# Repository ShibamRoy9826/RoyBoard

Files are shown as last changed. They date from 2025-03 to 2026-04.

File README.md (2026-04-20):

# RoyBoard 





## Description

Its a mechanical keyboard that I made from scratch! Its basically a 75% tenkeyless keyboard with 81 keys in total, with 3 additional rotary encoders for different tasks such as volume control, brightness control and scrolling, of course these functionalities are subject to change. It has a few neopixels too! not per key RGB though, because i rarely use backlight and it was pretty daunting to route them up, considering the fact that i just started hardware back then, the ones which I have are meant for aesthetics. Currently, I have dropped the plan to solder them because I mirrored the pinouts and it will be a terrible mess to solder them, I guess I am still satisfied with how it turned out though. 

## Features 

- ~Includes RGB lights (not per key RGB)~ (Not soldered)
- Has 3 rotary encoders for different functions
    - Media playback
    - Brightness
    - Volume
    - Scrolling
    - DWM tag switching(Any other wm works)
- 2 Layer keyboard (as of now, may add more in future if needed)
- Consists of 81 keys in total + 3 clickable rotary encoders, a 75%-ish Tenkeyless keyboard
- 5 degree tilt stand for a comfortable typing experience

## Real Life Pics

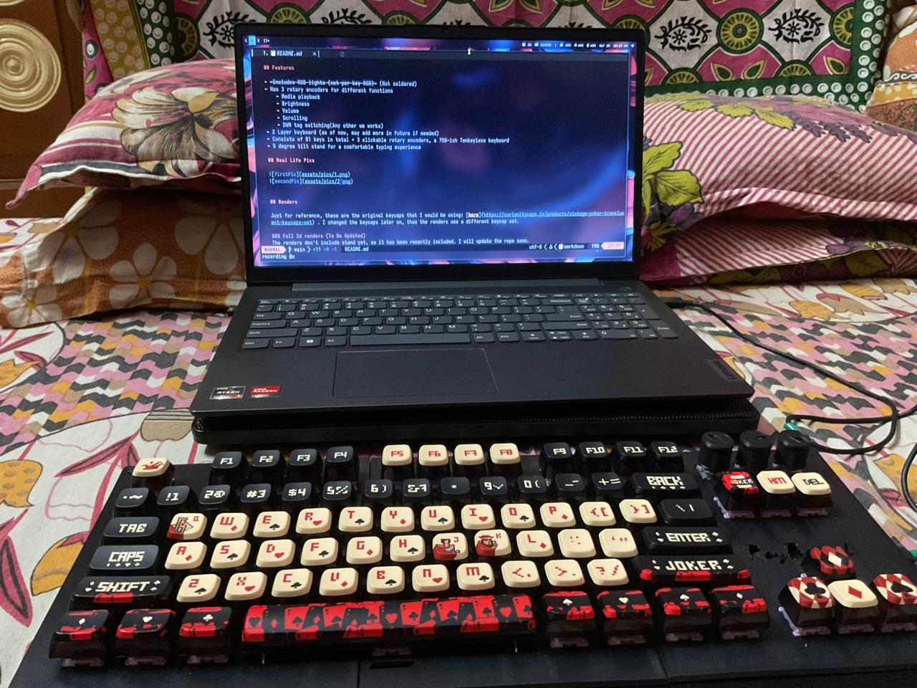
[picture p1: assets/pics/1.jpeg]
firstPic


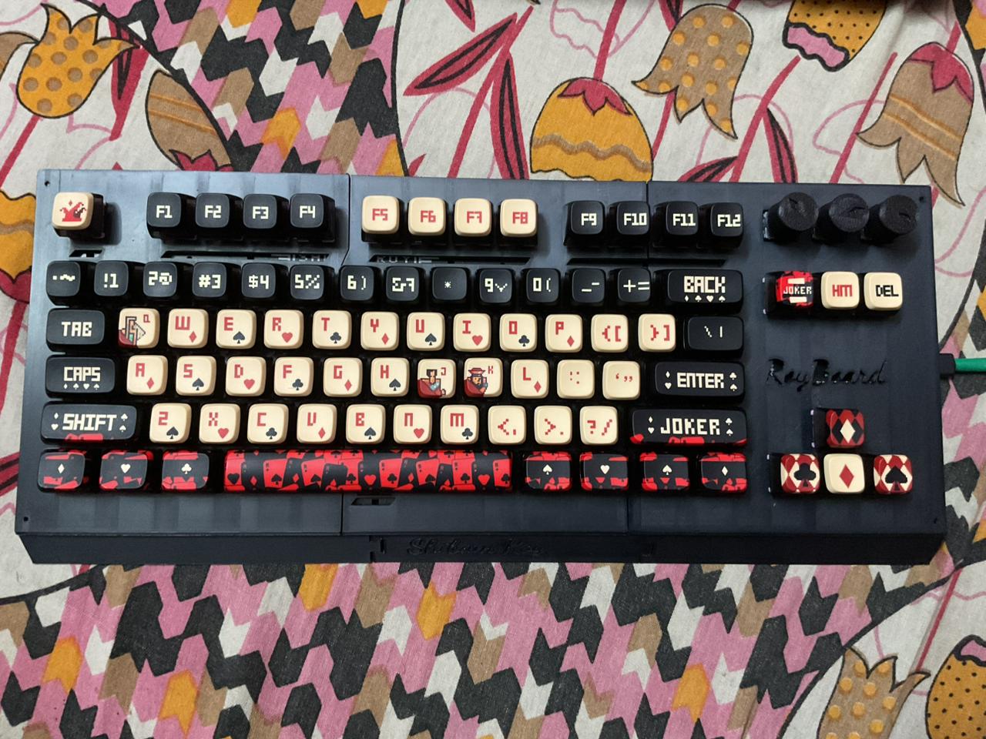
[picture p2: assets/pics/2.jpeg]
secondPic


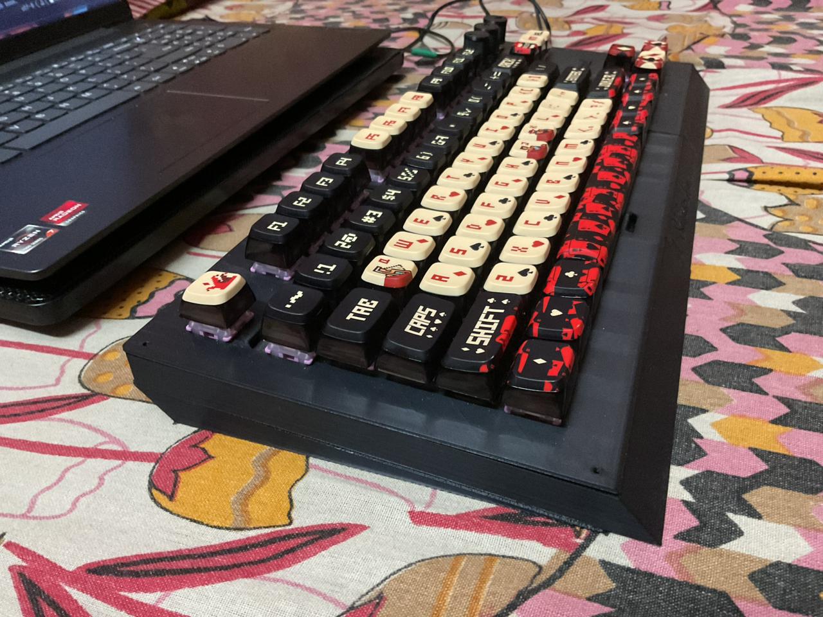
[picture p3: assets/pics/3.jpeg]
thirdPic


## Renders

Just for reference, these are the original keycaps that I would be using: [here](https://curiositycaps.in/products/vintage-poker-translucent-keycaps-set) . I changed the keycaps later on, thus the renders use a different keycap set.

### Full 3d renders (To Be Updated)
The renders don't include stand yet, as it has been recently included. I will update the repo soon.

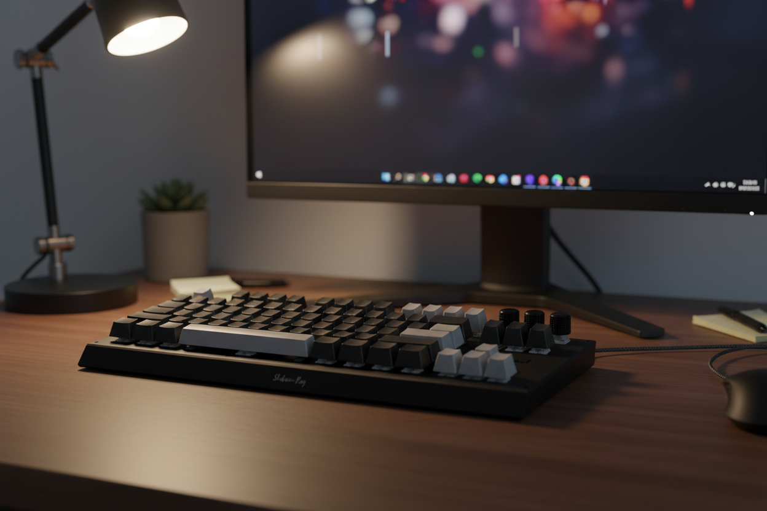
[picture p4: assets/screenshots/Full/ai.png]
ai


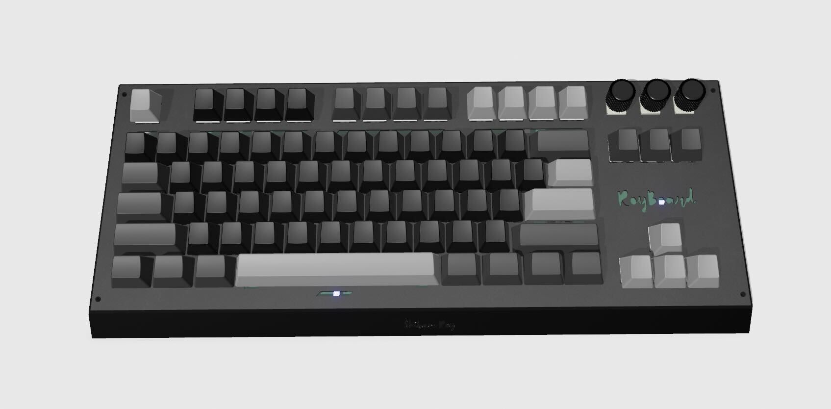
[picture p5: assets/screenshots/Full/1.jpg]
first


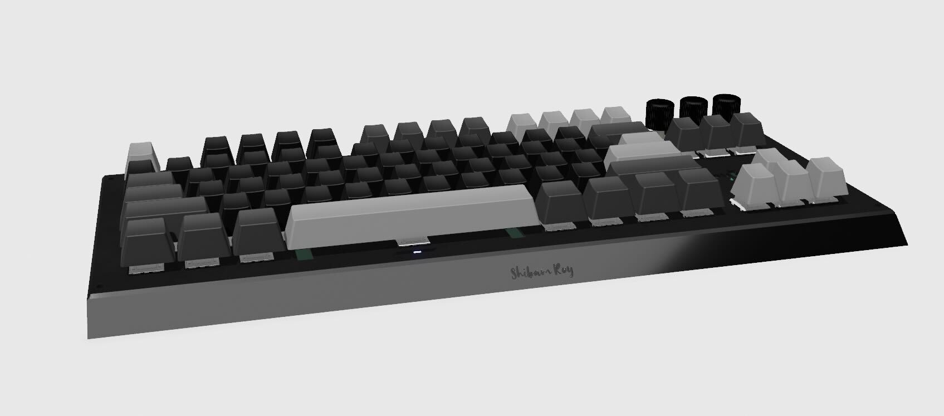
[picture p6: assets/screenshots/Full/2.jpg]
second


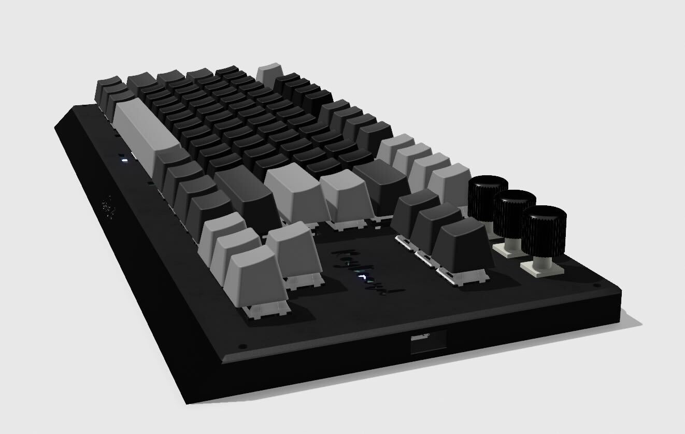
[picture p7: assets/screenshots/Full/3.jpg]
third


### Bottom case

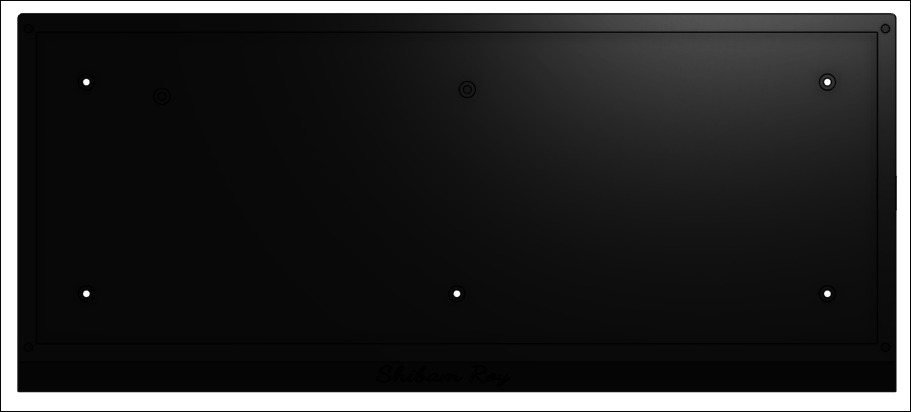
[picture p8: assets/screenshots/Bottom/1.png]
bottom

bottom1
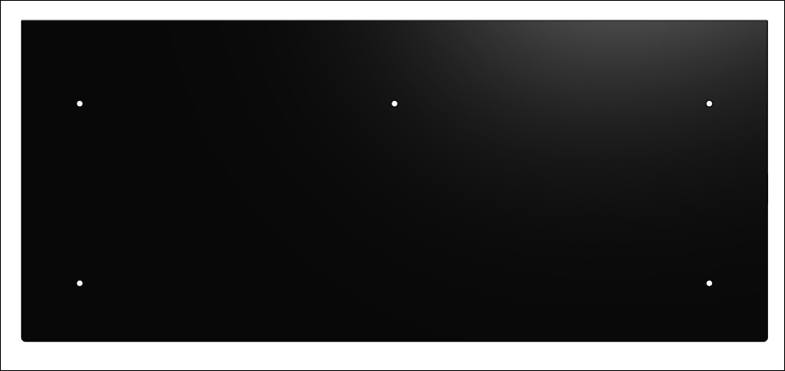
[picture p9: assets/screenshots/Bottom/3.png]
bottom2


### Top plate

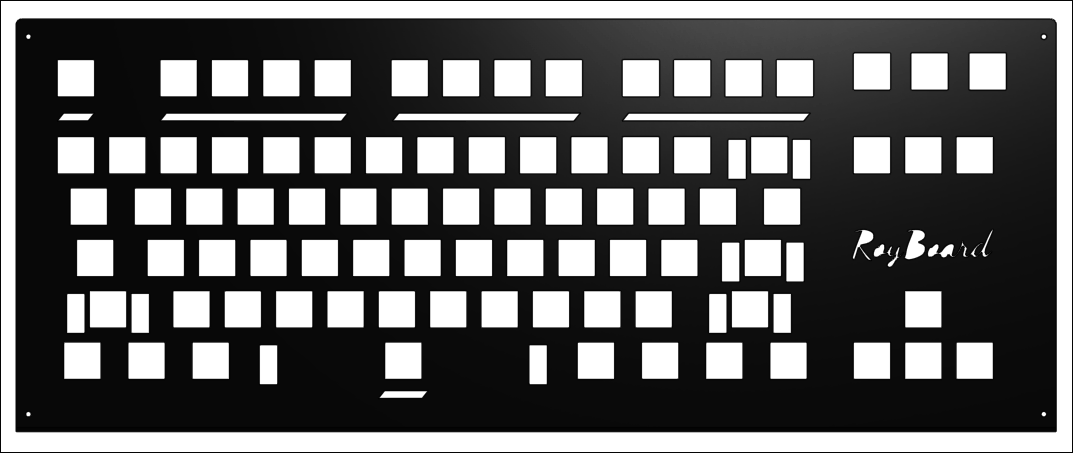
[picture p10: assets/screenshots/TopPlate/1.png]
top


### Stand

stand1
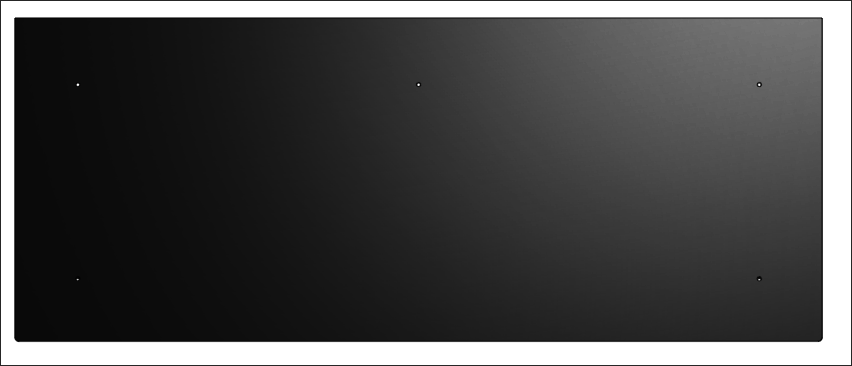
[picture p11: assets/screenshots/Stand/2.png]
stand2

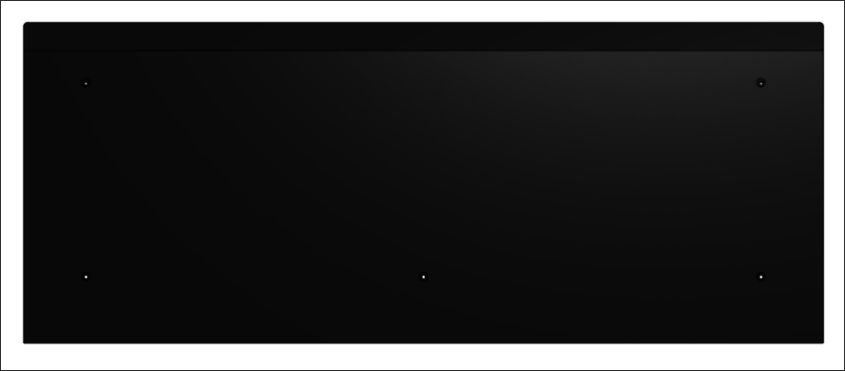
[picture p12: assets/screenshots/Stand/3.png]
stand3


### PCB 3D (Front)

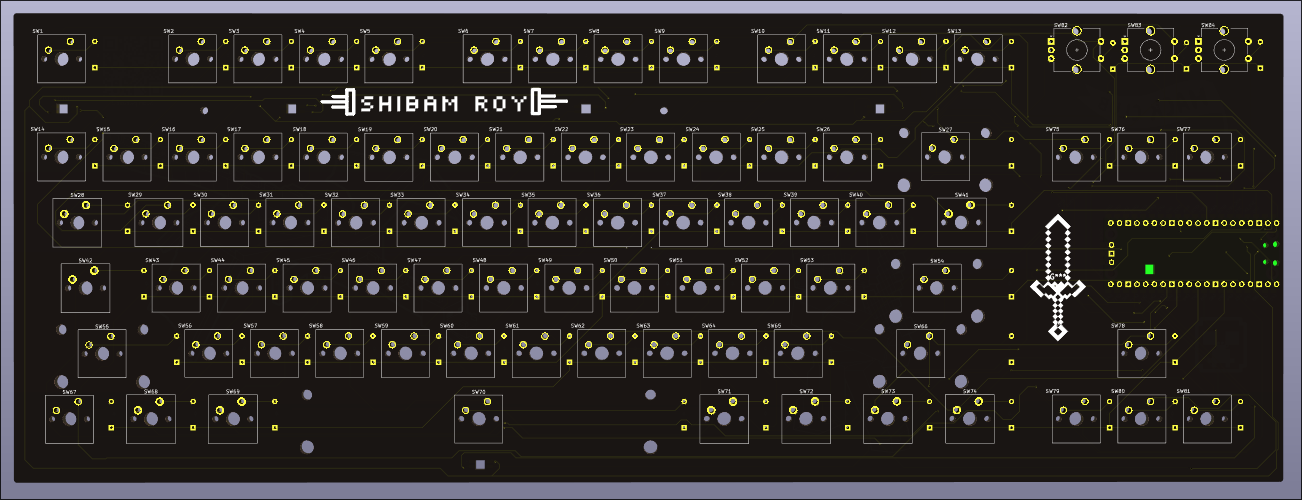
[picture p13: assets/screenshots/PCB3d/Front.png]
3dfront


### PCB 3D (Back)

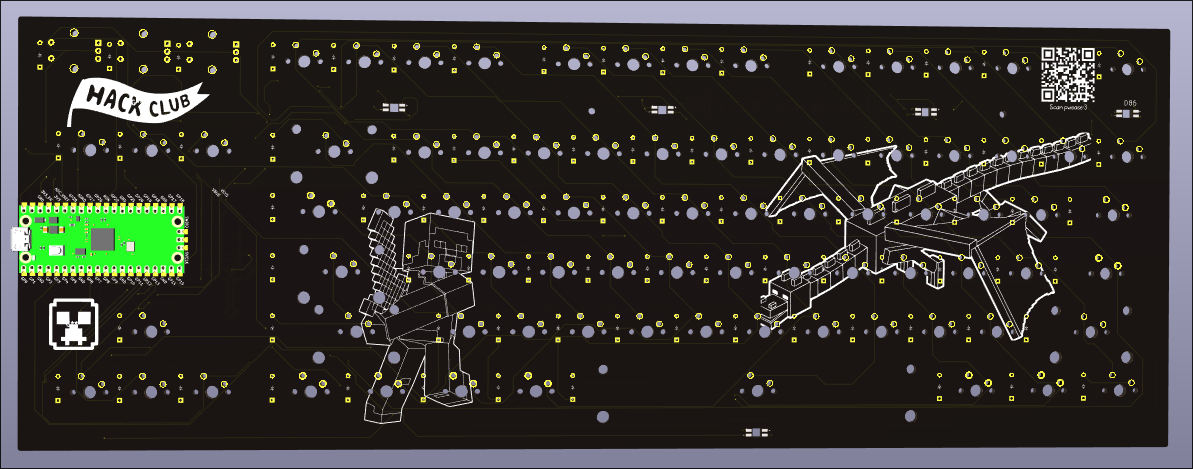
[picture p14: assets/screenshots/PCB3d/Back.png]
3dback


### Schematic

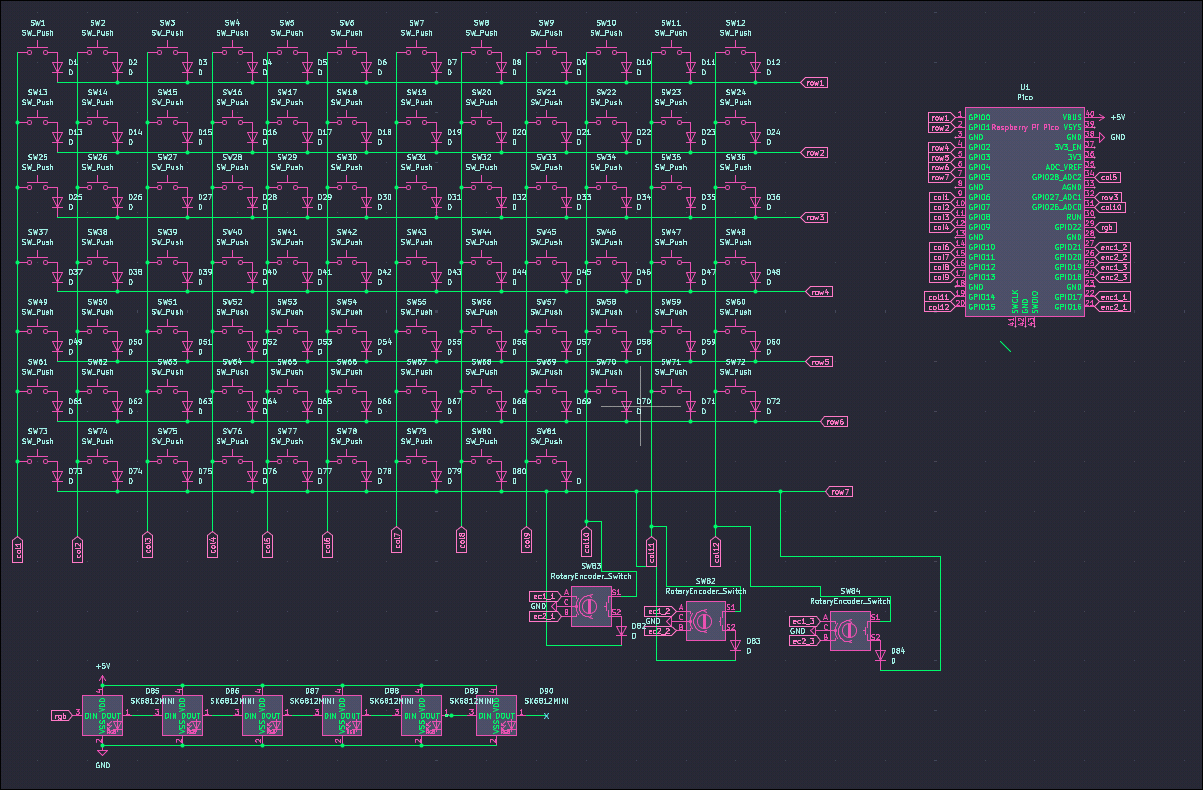
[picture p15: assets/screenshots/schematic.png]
schematic


### Layout

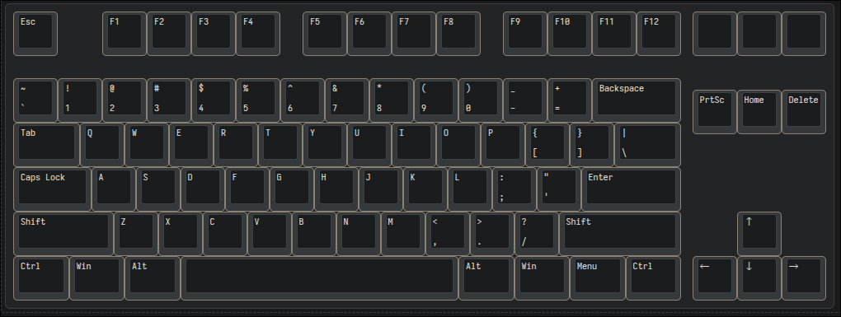
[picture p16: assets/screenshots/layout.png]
layout


### PCB

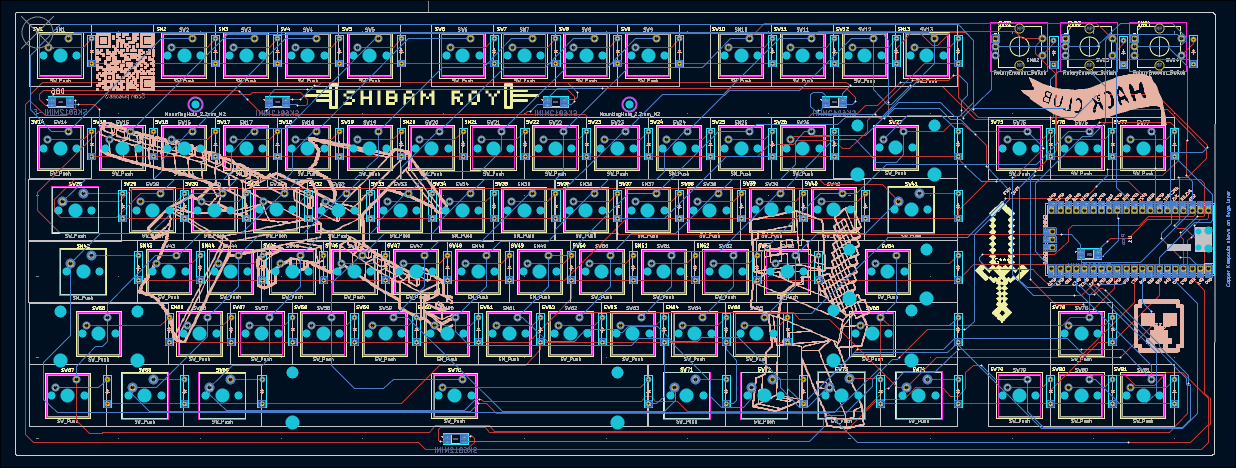
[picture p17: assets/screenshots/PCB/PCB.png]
pcb


### PCB Back

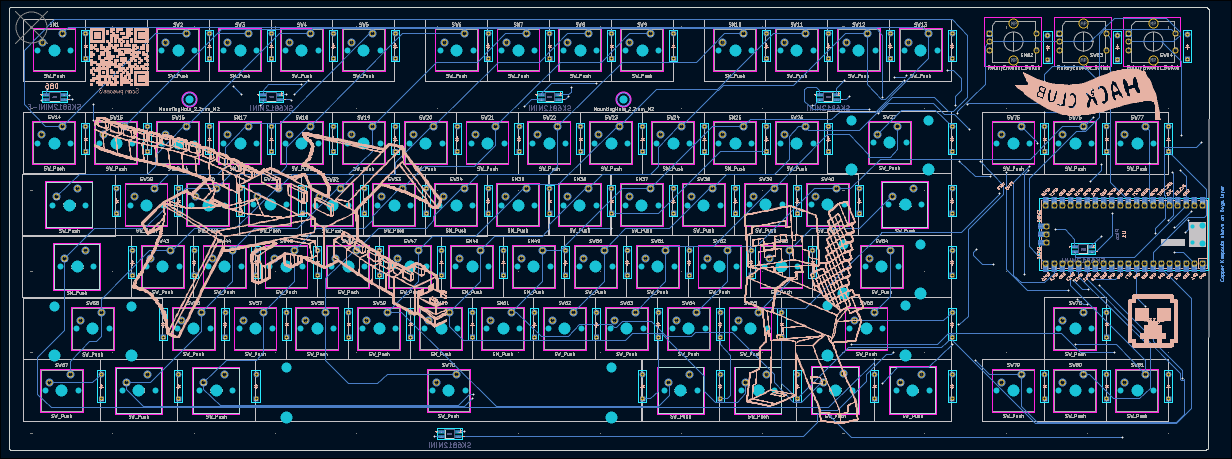
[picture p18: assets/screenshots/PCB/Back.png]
pcb back


### PCB Front

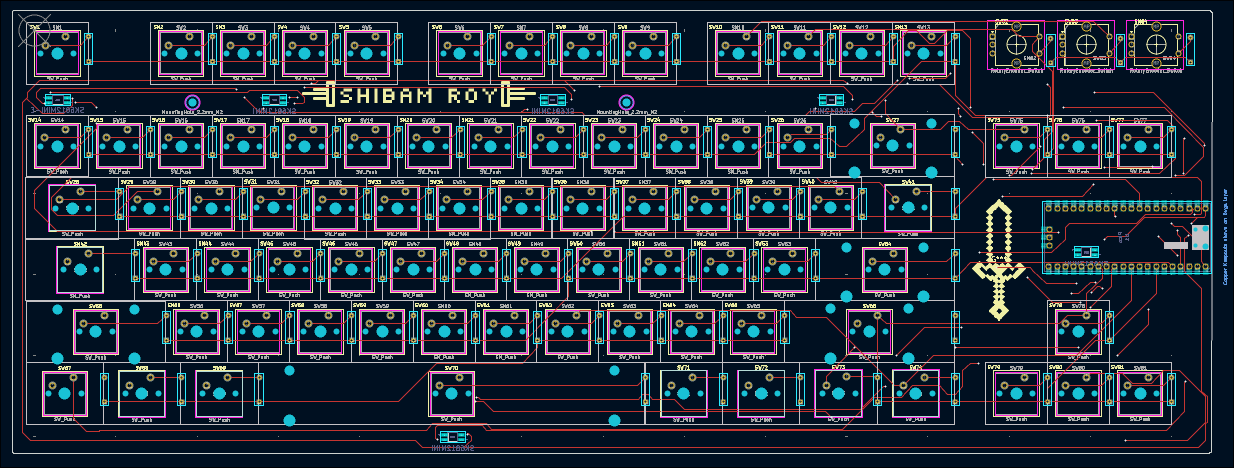
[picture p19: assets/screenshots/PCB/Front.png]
pcb front


## What tools did I use? 

- [kiCad](https://www.kicad.org/) : For PCB designing
- [shapr3d](https://www.shapr3d.com/) (Mostly) & [OnShape](https://onshape.com): For Case designing
- [keyboard-layout-editor](keyboard-layout-editor.com): For layout designing

## Firmware
Written in QMK, I have shifted the firmware to another repository, so please check that out [here](https://github.com/ShibamRoy9826/RoyBoard-firmware)

## 3D models

You can check the 3d models out in this [public document of OnShape](https://cad.onshape.com/documents/ddc280e53ddd9ad94dbb1da3/w/e89386a56beb1bd36360f18a/e/ed9d1e719b4e163eef3ebe0b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)

## Dimensions

The entire keyboard is **385.65mm** x **166mm** (153 without the branding part) x **13mm**(+13.527mm with stand)

## Bill of materials

| Item name | Net Price(USD) | Net Price(INR) | Expected Net Price (INR) | Diff (INR) |
|:---|---:|---:|---:|---:|
| Vintage Poker Translucent Keycaps Set | 18.2  | 1599 | 1615.98 | -16.98 |
| Raspberry PI PICO | 5.06 | 449 | 449.28 | -0.28 |
| 1N4148 THT Diodes | 2.13 | 189 | 189.12 | -0.12 |
| EC11 Rotary Encoders | 4.48 | 406 | 397.78 | 8.22 |
| Gateron Weightlessness Switches | 39.53 | 3510 | 3509.87 | 0.13 |
| Durock Smokey Screw-In Stabilizers v2 | 18.13 | 1595 | 1609.76 | -14.76 |
| PCB | 66 | 5860 | 5860.14 | -0.14 |
| SK6812 MINI-E LEDs | 7.62 | 669.59 | 676.58 | -6.99 |
| M2 x 6 mm Heat inserts | 1.29 | 114.6  | 114.54 | 0.06 |
| M2 x 6 mm screws | nan | nan | nan | nan |
| 3D Prints | nan | nan | nan | nan |

**Total:** $162.44 (14,423 INR)

## To-Do 
- [x] ~Build it irl~
- [x] ~Do testing~
- [x] ~Upload new pics here~

## Contributing

Everyone is welcome to contribute to the code!
You can also raise an issue, or suggest any features that you think would be great :)

## License
Licensed under the MIT License. See [LICENSE](LICENSE) for more information.

> ✨ Please star this repository if you liked this project 😁

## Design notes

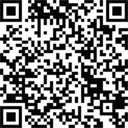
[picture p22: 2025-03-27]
PCB/assets/Silkscreen/NotRickRoll.png

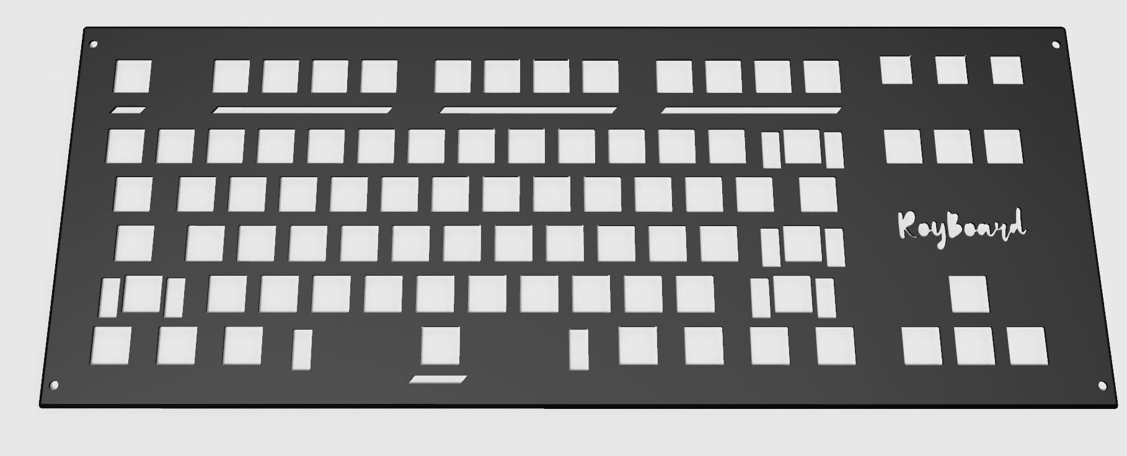
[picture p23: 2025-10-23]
assets/screenshots/Full/top.jpg

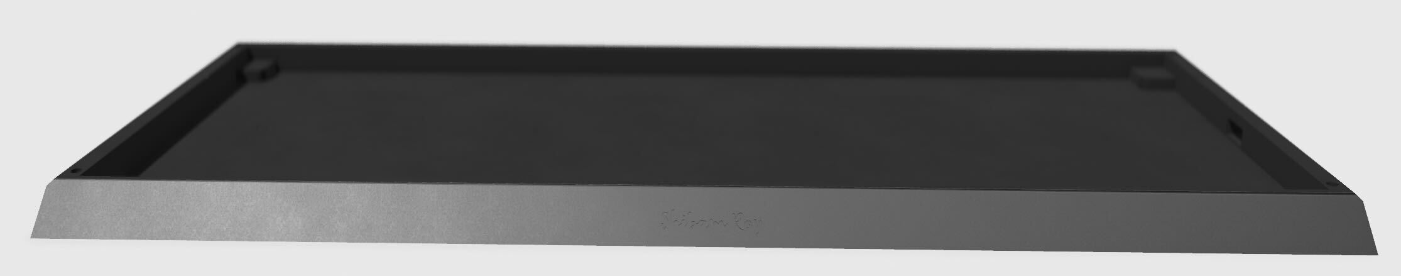
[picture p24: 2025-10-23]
assets/screenshots/Full/bottom.jpg

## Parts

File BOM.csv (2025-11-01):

Item Name | Category | Quantity | Price per unit (USD) | Price per unit (INR) | Shipping price + Tax (USD) | Shipping Price + Tax(INR) | Net Price(USD) | Net Price(INR) | Link
Vintage Poker Translucent Keycaps Set | Keycaps | 1 | 18.2 | 1599 | 0 | 0 | 18.2 | 1599 | https://curiositycaps.in/products/vintage-poker-translucent-keycaps-set
Raspberry PI PICO | MCU | 1 |  | 449 | 0 | 0 | 5.06 | 449 | https://www.amazon.in/Raspberry-Pi-Headers-Soldered-Micro/dp/B08WPNM7JB
1N4148 THT Diodes | Diodes | 100 | 0.01 | 0.99 | 1.01 | 90 | 2.13 | 189 | https://www.amazon.in/dp/B084ZP5BJ3?ref_=cm_sw_r_cp_ud_dp_YPW3WFYTE31QA18570D1&_encoding=UTF8&psc=1
EC11 Rotary Encoders | Rotary encoders | 4 | 1 | 89 | 0.57 | 50 | 4.48 | 406 | https://www.amazon.in/dp/B0888RVZSN?ref_=cm_sw_r_cp_ud_dp_ECM6496E6Q914JPQP2XQ&_encoding=UTF8&psc=1
Gateron Weightlessness Switches | Switches | 90 | 0.44 | 39 | 0 | 0 | 39.53 | 3510 | https://neomacro.in/products/gateron-weightlessness-switch
Durock Smokey Screw-In Stabilizers v2 | Stabilizers | 1 set (4+1) | 18.13 | 1595 | 0 | 0 | 18.13 | 1595 | https://stackskb.com/store/durock-smokey-screw-in-stabilizers-v2/
PCB | PCB | 1 | 66 | 5860 | 0 | 0 | 66 | 5860 | https://www.pcbpower.com/page/pcb-fabrication
SK6812 MINI-E LEDs | Neopixels | 10 | 0.85 | 75.47 | 6.77 | 601.11 | 7.62 | 669.59 | https://www.lcsc.com/product-detail/C5149201.html
M2 x 6 mm Heat inserts | Heat inserts | 9 | 0.02 | 2.2 | 0.75 | 66.8 | 1.29 | 114.6 | https://onlyscrews.in/products/m2-x-6mm-brass-threaded-inserts
M2 x 6 mm screws | Screws | 9 | 0.02 | 2 | Included above | Included above | Included above | Included above | https://onlyscrews.in/products/m2-x-6mm-phillips-pan-head-ss-304-screw
3D Prints | 3d Prints | 3 |  |  |  |  |  |  | Print-Legion

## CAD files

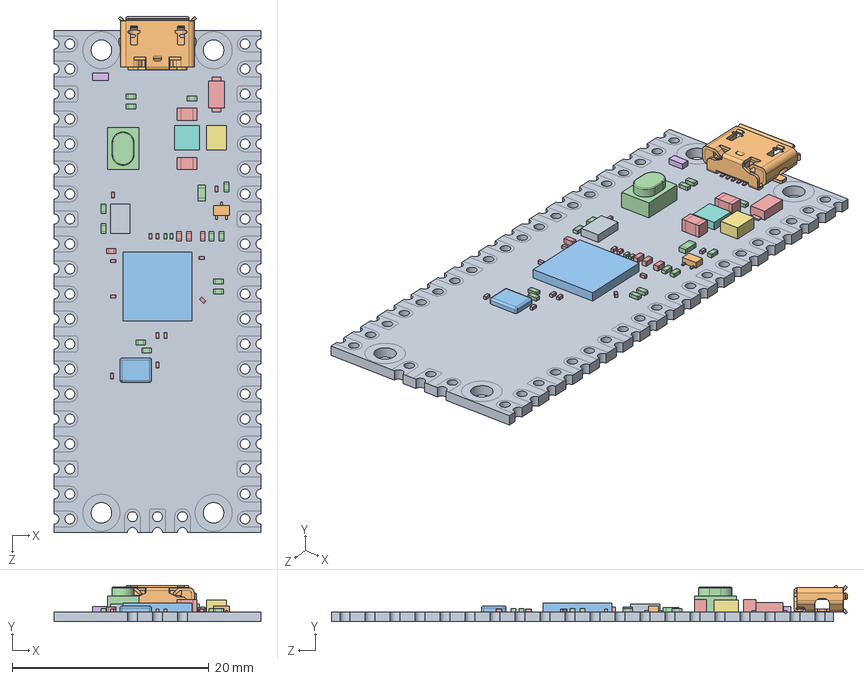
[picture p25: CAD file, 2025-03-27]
PCB/assets/3d/Raspberry Pi Pico-R3.SLDASM
21.0 x 3.69 x 52.4 mm
PCB, Raspberry Pi Pico-R3
MicroUSB Port, Raspberry Pi Pico-R3
RP2040 Microcontroller, Raspberry Pi Pico-R3
SW1, Tact Switch, Raspberry Pi Pico-R3
D1, Diode, Schottky, Raspberry Pi Pico-R3
D2, QSME-C194, LED, Raspberry Pi Pico-R3
L1, Inductor, Raspberry Pi Pico-R3
U2, RT6150B-33GQW, Buck Boost Converter, Raspberry Pi Pico-R3
U3, W25Q16JVUXIQ, Serial NOR Flash 16 Mbit, Raspberry Pi Pico-R3
Q1, MOSFET, DMG1012T, Raspberry Pi Pico-R3
X1, X12M000000S096, 12 Mhz Crystal Resonator, Raspberry Pi Pico-R3
SMD Resistor, Configurable, Raspberry Pi Pico-R3 x 15
SMD Capacitor, Configurable, Raspberry Pi Pico-R3 x 18

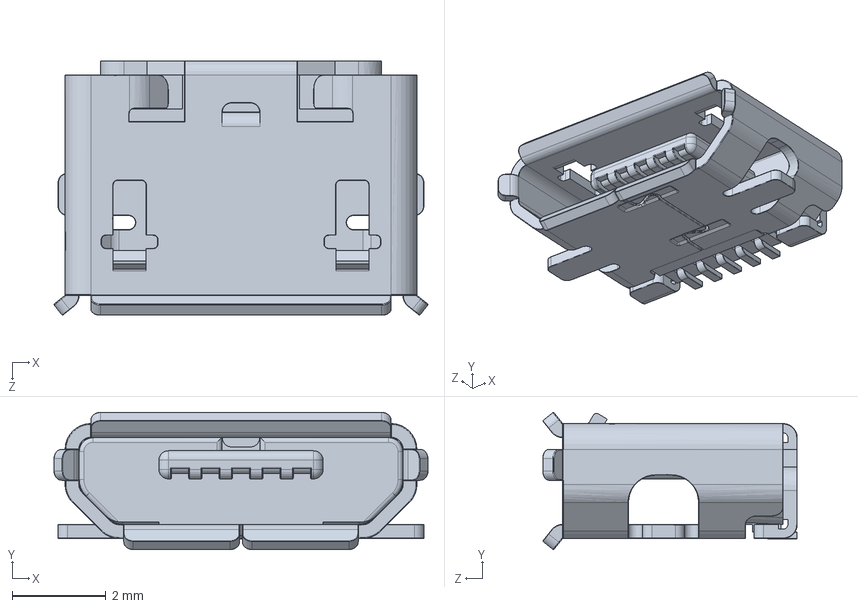
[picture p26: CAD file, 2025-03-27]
PCB/assets/3d/MicroUSB Port, Raspberry Pi Pico-R3.SLDPRT
7.97 x 2.92 x 5.43 mm

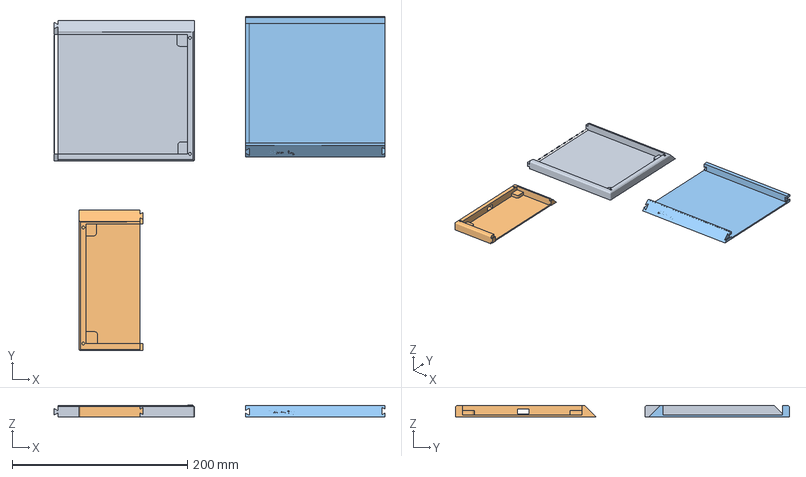
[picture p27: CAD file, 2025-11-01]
printing/Bottom-RoyBoard.3mf
378.2 x 382.0 x 13.2 mm
Bottom-RoyBoard.stl_A
Bottom-RoyBoard.stl_B_A
Bottom-RoyBoard.stl_B_B

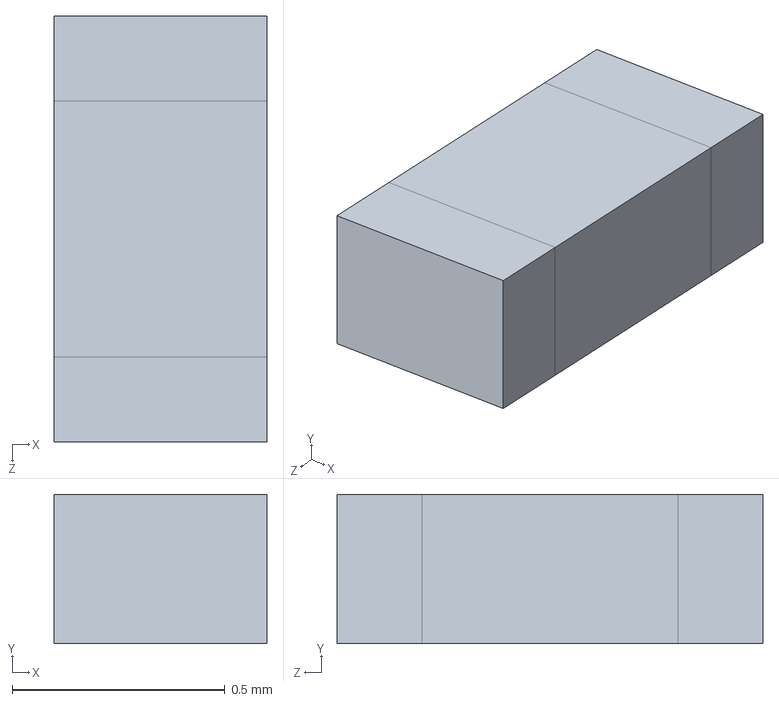
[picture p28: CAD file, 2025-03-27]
PCB/assets/3d/SMD Resistor, Configurable, Raspberry Pi Pico-R3.SLDPRT
0.5 x 0.35 x 1.00 mm

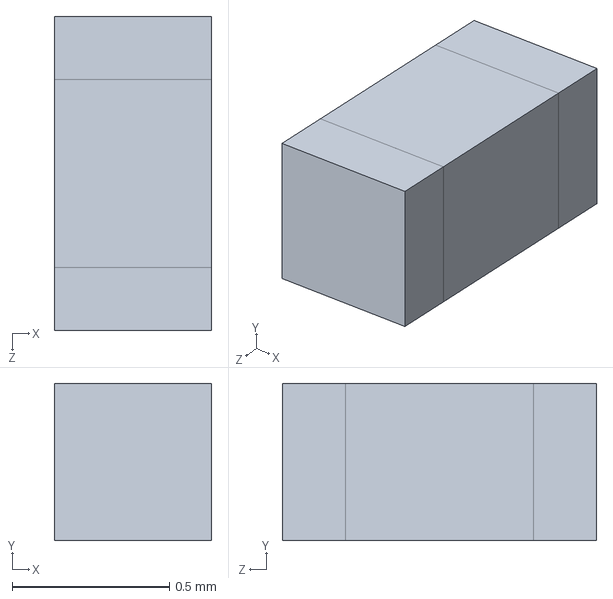
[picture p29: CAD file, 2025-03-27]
PCB/assets/3d/SMD Capacitor, Configurable, Raspberry Pi Pico-R3.SLDPRT
0.5 x 0.5 x 1.00 mm

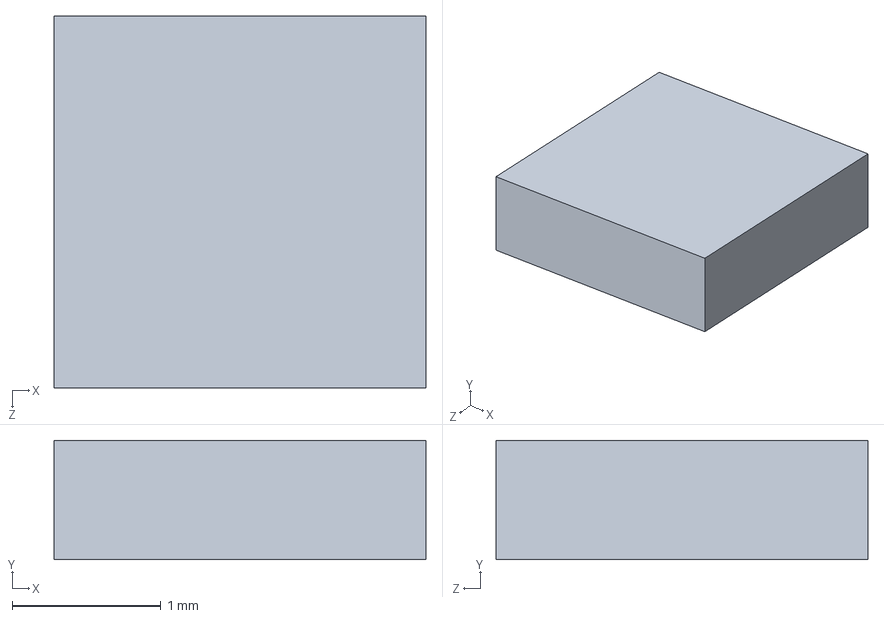
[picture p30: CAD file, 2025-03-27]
PCB/assets/3d/U2, RT6150B-33GQW, Buck Boost Converter, Raspberry Pi Pico-R3.SLDPRT
2.50 x 0.8 x 2.50 mm

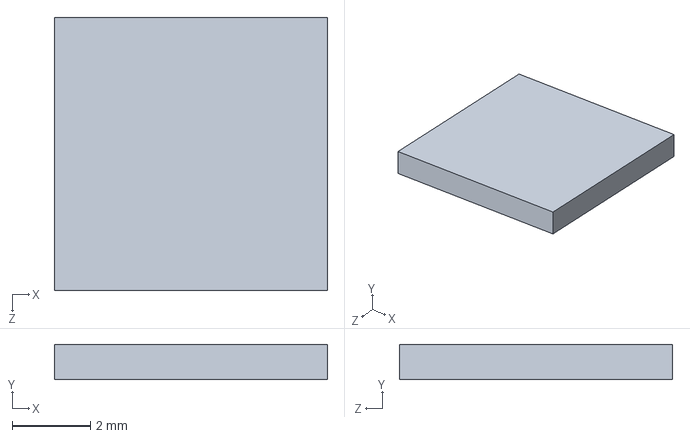
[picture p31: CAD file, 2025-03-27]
PCB/assets/3d/RP2040 Microcontroller, Raspberry Pi Pico-R3.SLDPRT
7.00 x 0.9 x 7.00 mm

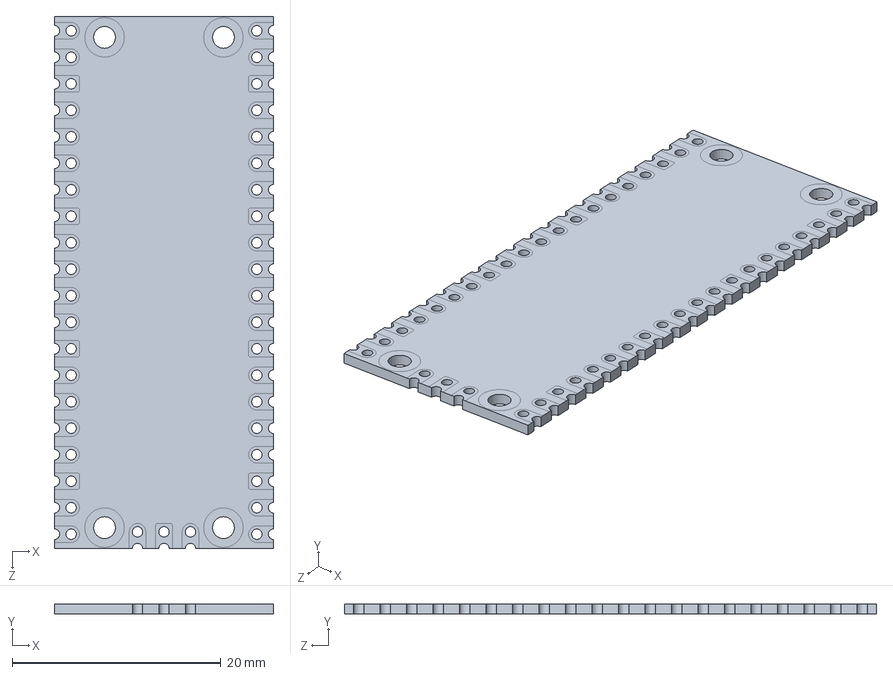
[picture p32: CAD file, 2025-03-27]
PCB/assets/3d/PCB, Raspberry Pi Pico-R3.SLDPRT
21.0 x 1.00 x 51.0 mm

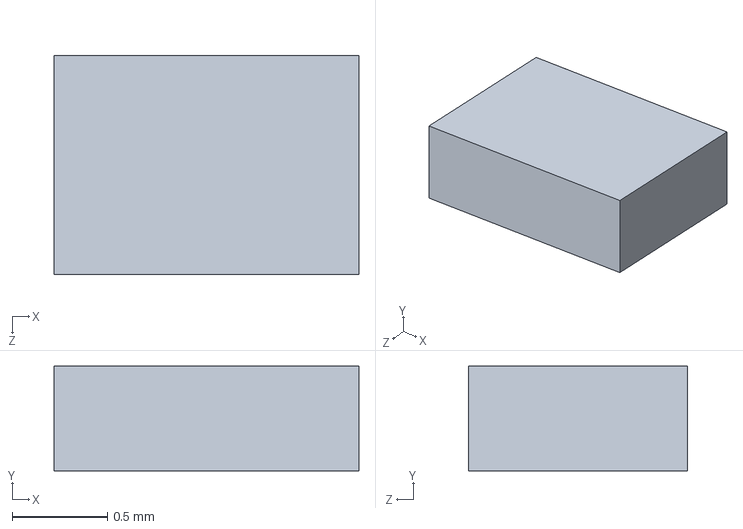
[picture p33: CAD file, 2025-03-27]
PCB/assets/3d/D2, QSME-C194, LED, Raspberry Pi Pico-R3.SLDPRT
1.60 x 0.55 x 1.15 mm

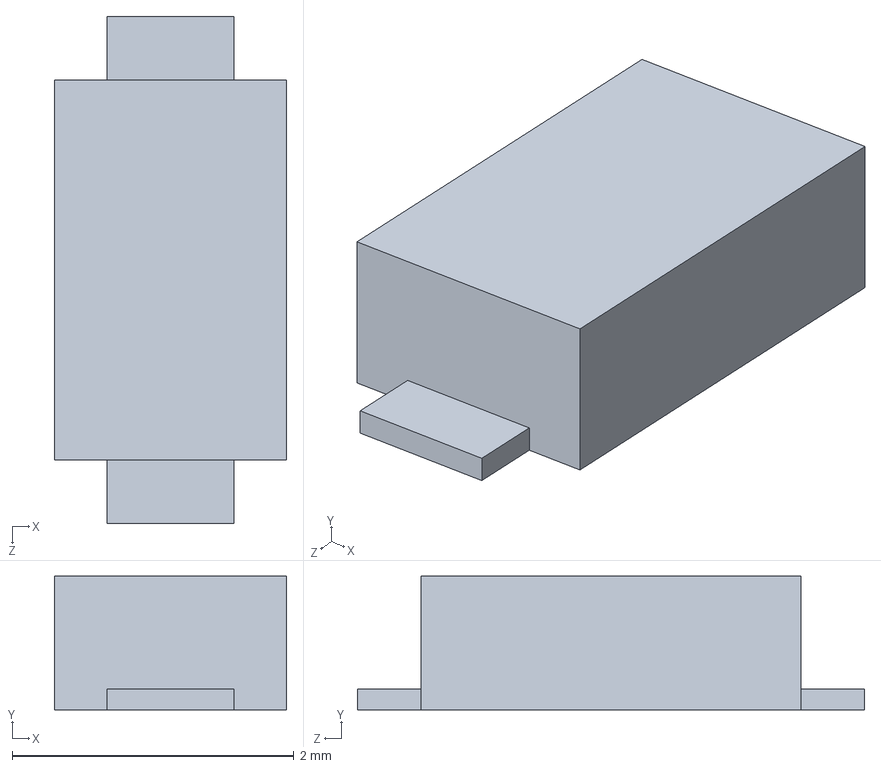
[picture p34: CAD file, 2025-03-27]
PCB/assets/3d/D1, Diode, Schottky, Raspberry Pi Pico-R3.SLDPRT
1.65 x 0.95 x 3.60 mm

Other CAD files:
CAD/Royboard-Full.step
PCB/assets/Footprints/SK6812/SK6812MINI-E.step
PCB/assets/Footprints/SK6812MINI-E.step
PCB/assets/Footprints/SK6812MINI-E/SK6812-E.step
CAD/Stand.step
CAD/Circuit.step
CAD/TopPlate.step
CAD/Bottom.step
PCB/assets/3d/L1, Inductor, Raspberry Pi Pico-R3.SLDPRT
PCB/assets/3d/Q1, MOSFET, DMG1012T, Raspberry Pi Pico-R3.SLDPRT
PCB/assets/3d/Raspberry Pi Pico-R3.x_b
PCB/assets/3d/SW1, Tact Switch, Raspberry Pi Pico-R3.SLDPRT
PCB/assets/3d/U3, W25Q16JVUXIQ, Serial NOR Flash 16 Mbit, Raspberry Pi Pico-R3.SLDPRT
PCB/assets/3d/X1, X12M000000S096, 12 Mhz Crystal Resonator, Raspberry Pi Pico-R3.SLDPRT

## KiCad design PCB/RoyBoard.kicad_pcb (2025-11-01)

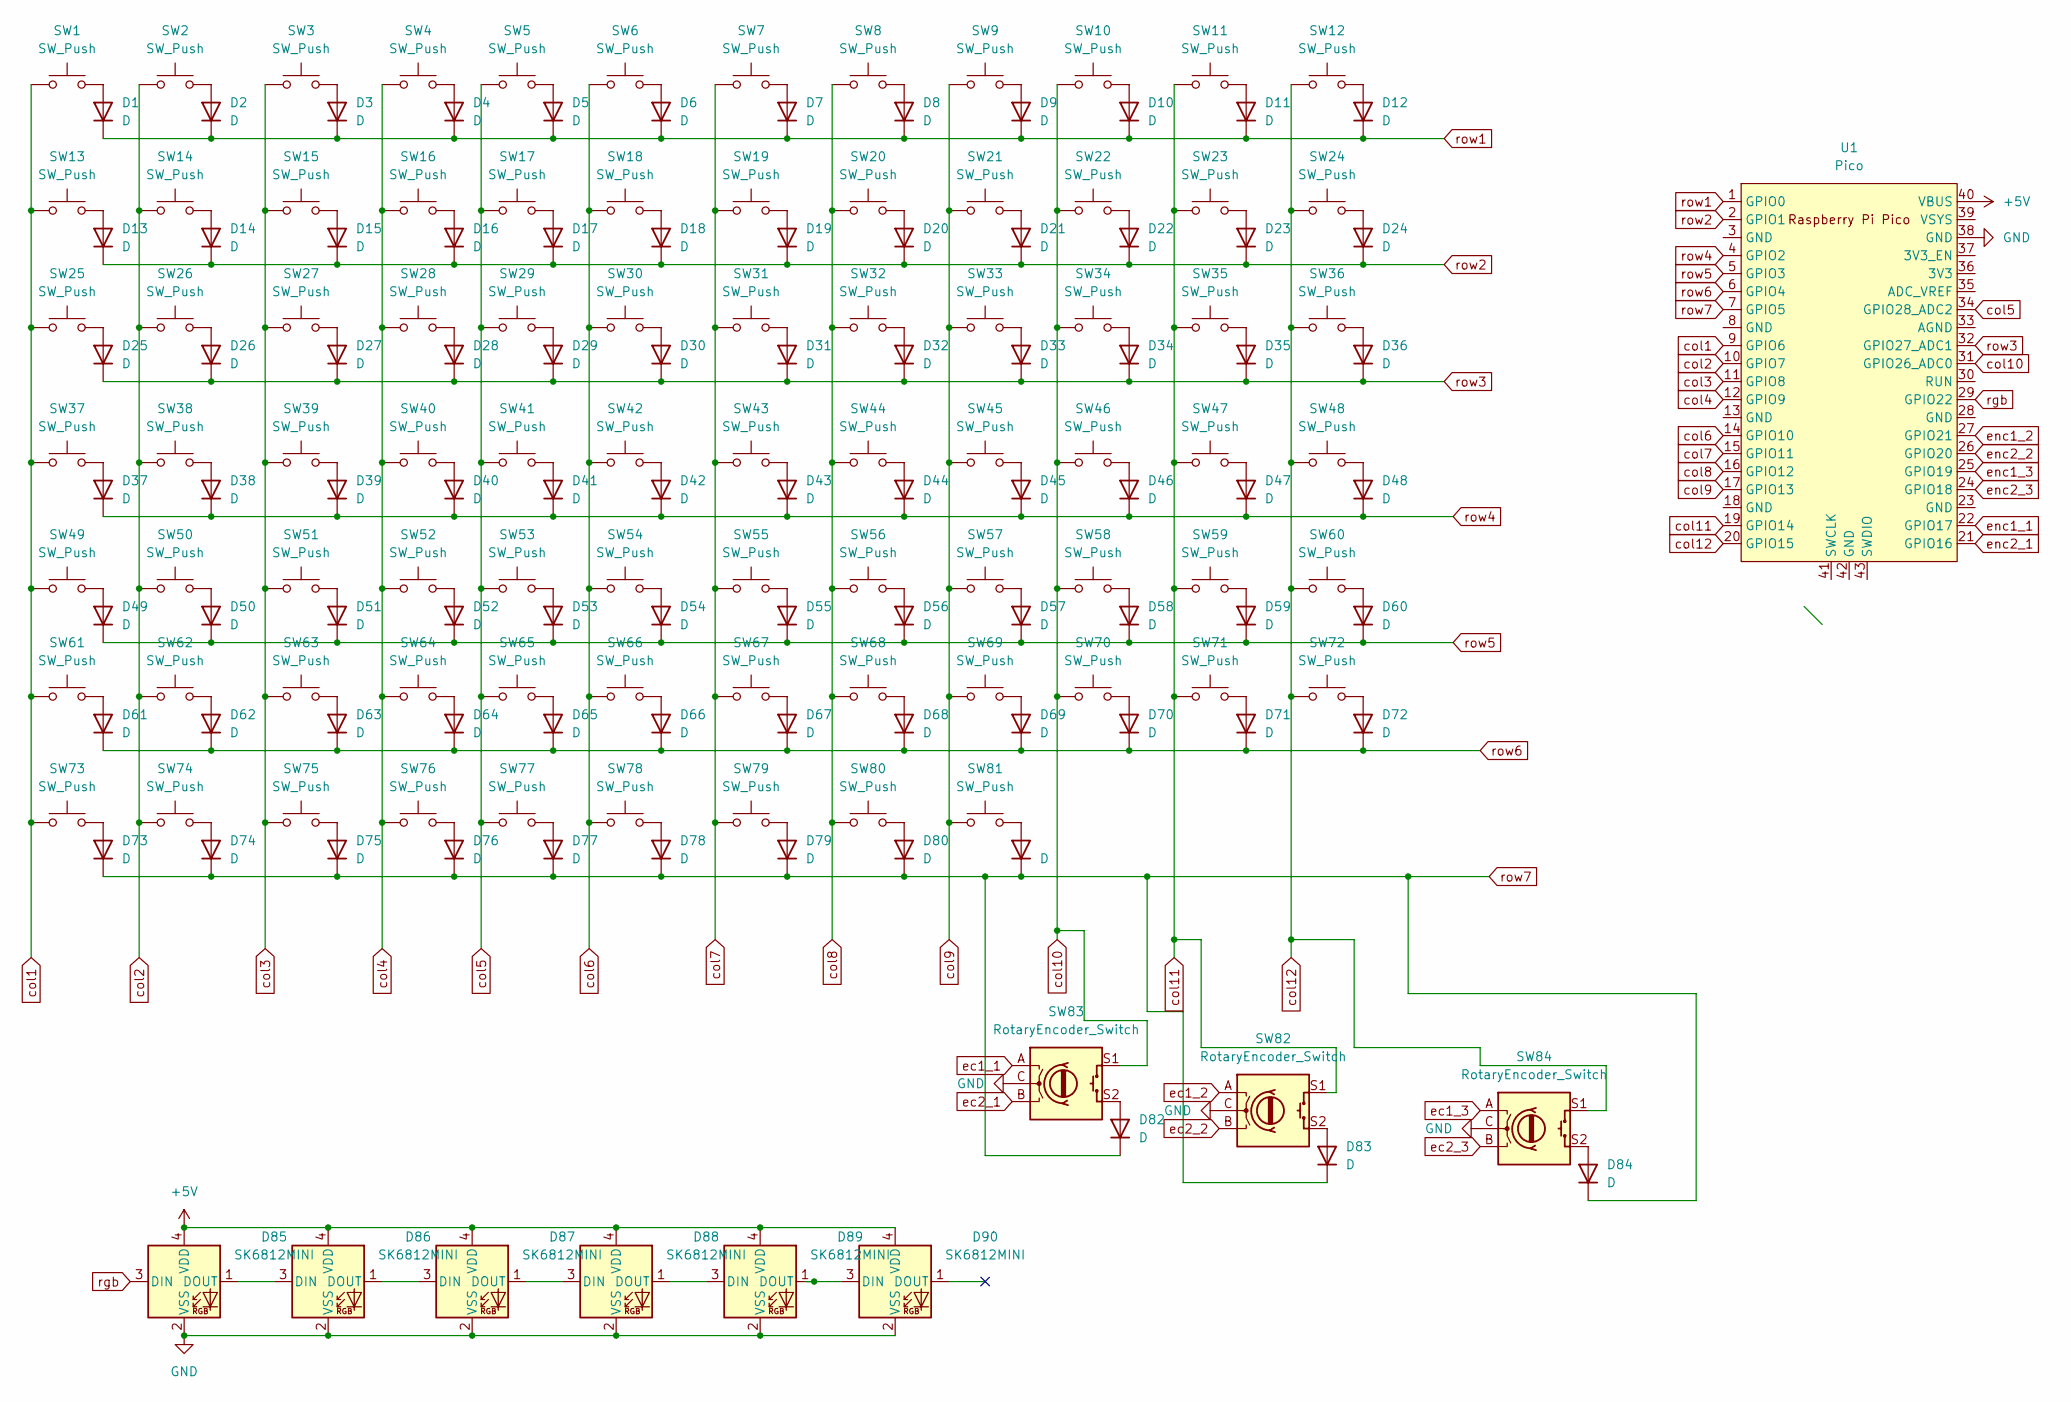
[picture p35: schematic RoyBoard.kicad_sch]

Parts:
D1, D2, D3, D4, D5, D6, D7, D8, D9, D10, D11, D12, D13, D14, D15, D16, D17, D18, D19, D20, D21, D22, D23, D24, D25, D26, D27, D28, D29, D30, D31, D32, D33, D34, D35, D36, D37, D38, D39, D40, D41, D42, D43, D44, D45, D46, D47, D48, D49, D50, D51, D52, D53, D54, D55, D56, D57, D58, D59, D60, D61, D62, D63, D64, D65, D66, D67, D68, D69, D70, D71, D72, D73, D74, D75, D76, D77, D78, D79, D80, D81, D82, D83, D84: D; Diode_DO-35
D85, D86, D87, D88, D89, D90: SK6812MINI; LED_SK6812MINI_PLCC4_3.5x3.5mm_P1.75mm
SW1, SW2, SW3, SW4, SW5, SW6, SW7, SW8, SW9, SW10, SW11, SW12, SW13, SW14, SW15, SW16, SW17, SW18, SW19, SW20, SW21, SW22, SW23, SW24, SW25, SW26, SW29, SW30, SW31, SW32, SW33, SW34, SW35, SW36, SW37, SW38, SW39, SW40, SW43, SW44, SW45, SW46, SW47, SW48, SW49, SW50, SW51, SW52, SW53, SW56, SW57, SW58, SW59, SW60, SW61, SW62, SW63, SW64, SW65, SW75, SW76, SW77, SW78, SW79, SW80, SW81: SW_Push; SW_Cherry_MX_1.00u_PCB
SW27: SW_Push; SW_Cherry_MX_PCB_2.00u
SW28, SW41: SW_Push; SW_Cherry_MX_PCB_1.50u
SW42: SW_Push; SW_Cherry_MX_PCB_1.75u
SW54, SW55: SW_Push; SW_Cherry_MX_2.25u_PCB
SW66: SW_Push; SW_Cherry_MX_2.75u_PCB
SW67: SW_Push; SW_Cherry_MX_1.25u_PCB
SW68, SW69, SW71, SW72, SW73, SW74: SW_Push; SW_Cherry_MX_PCB_1.25u
SW70: SW_Push; SW_Cherry_MX_6.25u_PCB
SW82, SW83, SW84: RotaryEncoder_Switch; RotaryEncoder_Alps_EC12E-Switch_Vertical_H20mm_CircularMoun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
U1: Pico; RPi_Pico_SMD_TH

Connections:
+5V: D85.4 (VDD), D86.4 (VDD), D87.4 (VDD), D88.4 (VDD), D89.4 (VDD), D90.4 (VDD), U1.40 (VBUS)
GND: D85.2 (VSS), D86.2 (VSS), D87.2 (VSS), D88.2 (VSS), D89.2 (VSS), D90.2 (VSS), SW82.C, SW83.C, SW84.C, U1.38 (GND)
unnamed: D1.2 (A), SW1.2
unnamed: D2.2 (A), SW2.2
unnamed: D3.2 (A), SW3.2
unnamed: D4.2 (A), SW4.2
unnamed: D5.2 (A), SW5.2
unnamed: D6.2 (A), SW6.2
unnamed: D7.2 (A), SW7.2
unnamed: D8.2 (A), SW8.2
unnamed: D9.2 (A), SW9.2
unnamed: D10.2 (A), SW10.2
unnamed: D11.2 (A), SW11.2
unnamed: D12.2 (A), SW12.2
unnamed: D13.2 (A), SW13.2
unnamed: D14.2 (A), SW14.2
unnamed: D15.2 (A), SW15.2
unnamed: D16.2 (A), SW16.2
unnamed: D17.2 (A), SW17.2
unnamed: D18.2 (A), SW18.2
unnamed: D19.2 (A), SW19.2
unnamed: D20.2 (A), SW20.2
unnamed: D21.2 (A), SW21.2
unnamed: D22.2 (A), SW22.2
unnamed: D23.2 (A), SW23.2
unnamed: D24.2 (A), SW24.2
unnamed: D25.2 (A), SW25.2
unnamed: D26.2 (A), SW26.2
unnamed: D27.2 (A), SW27.2
unnamed: D28.2 (A), SW28.2
unnamed: D29.2 (A), SW29.2
unnamed: D30.2 (A), SW30.2
unnamed: D31.2 (A), SW31.2
unnamed: D32.2 (A), SW32.2
unnamed: D33.2 (A), SW33.2
unnamed: D34.2 (A), SW34.2
unnamed: D35.2 (A), SW35.2
unnamed: D36.2 (A), SW36.2
unnamed: D37.2 (A), SW37.2
unnamed: D38.2 (A), SW38.2
unnamed: D39.2 (A), SW39.2
unnamed: D40.2 (A), SW40.2
unnamed: D41.2 (A), SW41.2
unnamed: D42.2 (A), SW42.2
unnamed: D43.2 (A), SW43.2
unnamed: D44.2 (A), SW44.2
unnamed: D45.2 (A), SW45.2
unnamed: D46.2 (A), SW46.2
unnamed: D47.2 (A), SW47.2
unnamed: D48.2 (A), SW48.2
unnamed: D49.2 (A), SW49.2
unnamed: D50.2 (A), SW50.2
unnamed: D51.2 (A), SW51.2
unnamed: D52.2 (A), SW52.2
unnamed: D53.2 (A), SW53.2
unnamed: D54.2 (A), SW54.2
unnamed: D55.2 (A), SW55.2
unnamed: D56.2 (A), SW56.2
unnamed: D57.2 (A), SW57.2
unnamed: D58.2 (A), SW58.2
unnamed: D59.2 (A), SW59.2
unnamed: D60.2 (A), SW60.2
unnamed: D61.2 (A), SW61.2
unnamed: D62.2 (A), SW62.2
unnamed: D63.2 (A), SW63.2
unnamed: D64.2 (A), SW64.2
unnamed: D65.2 (A), SW65.2
unnamed: D66.2 (A), SW66.2
unnamed: D67.2 (A), SW67.2
unnamed: D68.2 (A), SW68.2
unnamed: D69.2 (A), SW69.2
unnamed: D70.2 (A), SW70.2
unnamed: D71.2 (A), SW71.2
unnamed: D72.2 (A), SW72.2
unnamed: D73.2 (A), SW73.2
unnamed: D74.2 (A), SW74.2
unnamed: D75.2 (A), SW75.2
unnamed: D76.2 (A), SW76.2
unnamed: D77.2 (A), SW77.2
unnamed: D78.2 (A), SW78.2
unnamed: D79.2 (A), SW79.2
unnamed: D80.2 (A), SW80.2
unnamed: D81.2 (A), SW81.2
unnamed: D82.2 (A), SW83.S2
unnamed: D83.2 (A), SW82.S2
unnamed: D84.2 (A), SW84.S2
unnamed: D85.1 (DOUT), D86.3 (DIN)
unnamed: D86.1 (DOUT), D87.3 (DIN)
unnamed: D87.1 (DOUT), D88.3 (DIN)
unnamed: D88.1 (DOUT), D89.3 (DIN)
unnamed: D89.1 (DOUT), D90.3 (DIN)
col1: SW1.1, SW13.1, SW25.1, SW37.1, SW49.1, SW61.1, SW73.1, U1.9 (GPIO6)
col2: SW2.1, SW14.1, SW26.1, SW38.1, SW50.1, SW62.1, SW74.1, U1.10 (GPIO7)
col3: SW3.1, SW15.1, SW27.1, SW39.1, SW51.1, SW63.1, SW75.1, U1.11 (GPIO8)
col4: SW4.1, SW16.1, SW28.1, SW40.1, SW52.1, SW64.1, SW76.1, U1.12 (GPIO9)
col5: SW5.1, SW17.1, SW29.1, SW41.1, SW53.1, SW65.1, SW77.1, U1.34 (GPIO28_ADC2)
col6: SW6.1, SW18.1, SW30.1, SW42.1, SW54.1, SW66.1, SW78.1, U1.14 (GPIO10)
col7: SW7.1, SW19.1, SW31.1, SW43.1, SW55.1, SW67.1, SW79.1, U1.15 (GPIO11)
col8: SW8.1, SW20.1, SW32.1, SW44.1, SW56.1, SW68.1, SW80.1, U1.16 (GPIO12)
col9: SW9.1, SW21.1, SW33.1, SW45.1, SW57.1, SW69.1, SW81.1, U1.17 (GPIO13)
col10: SW10.1, SW22.1, SW34.1, SW46.1, SW58.1, SW70.1, SW83.S1, U1.31 (GPIO26_ADC0)
col11: SW11.1, SW23.1, SW35.1, SW47.1, SW59.1, SW71.1, SW82.S1, U1.19 (GPIO14)
col12: SW12.1, SW24.1, SW36.1, SW48.1, SW60.1, SW72.1, SW84.S1, U1.20 (GPIO15)
ec1_1: SW83.A
ec1_2: SW82.A
ec1_3: SW84.A
ec2_1: SW83.B
ec2_2: SW82.B
ec2_3: SW84.B
enc1_1: U1.22 (GPIO17)
enc1_2: U1.27 (GPIO21)
enc1_3: U1.25 (GPIO19)
enc2_1: U1.21 (GPIO16)
enc2_2: U1.26 (GPIO20)
enc2_3: U1.24 (GPIO18)
rgb: D85.3 (DIN), U1.29 (GPIO22)
row1: D1.1 (K), D2.1 (K), D3.1 (K), D4.1 (K), D5.1 (K), D6.1 (K), D7.1 (K), D8.1 (K), D9.1 (K), D10.1 (K), D11.1 (K), D12.1 (K), U1.1 (GPIO0)
row2: D13.1 (K), D14.1 (K), D15.1 (K), D16.1 (K), D17.1 (K), D18.1 (K), D19.1 (K), D20.1 (K), D21.1 (K), D22.1 (K), D23.1 (K), D24.1 (K), U1.2 (GPIO1)
row3: D25.1 (K), D26.1 (K), D27.1 (K), D28.1 (K), D29.1 (K), D30.1 (K), D31.1 (K), D32.1 (K), D33.1 (K), D34.1 (K), D35.1 (K), D36.1 (K), U1.32 (GPIO27_ADC1)
row4: D37.1 (K), D38.1 (K), D39.1 (K), D40.1 (K), D41.1 (K), D42.1 (K), D43.1 (K), D44.1 (K), D45.1 (K), D46.1 (K), D47.1 (K), D48.1 (K), U1.4 (GPIO2)
row5: D49.1 (K), D50.1 (K), D51.1 (K), D52.1 (K), D53.1 (K), D54.1 (K), D55.1 (K), D56.1 (K), D57.1 (K), D58.1 (K), D59.1 (K), D60.1 (K), U1.5 (GPIO3)
row6: D61.1 (K), D62.1 (K), D63.1 (K), D64.1 (K), D65.1 (K), D66.1 (K), D67.1 (K), D68.1 (K), D69.1 (K), D70.1 (K), D71.1 (K), D72.1 (K), U1.6 (GPIO4)
row7: D73.1 (K), D74.1 (K), D75.1 (K), D76.1 (K), D77.1 (K), D78.1 (K), D79.1 (K), D80.1 (K), D81.1 (K), D82.1 (K), D83.1 (K), D84.1 (K), U1.7 (GPIO5)

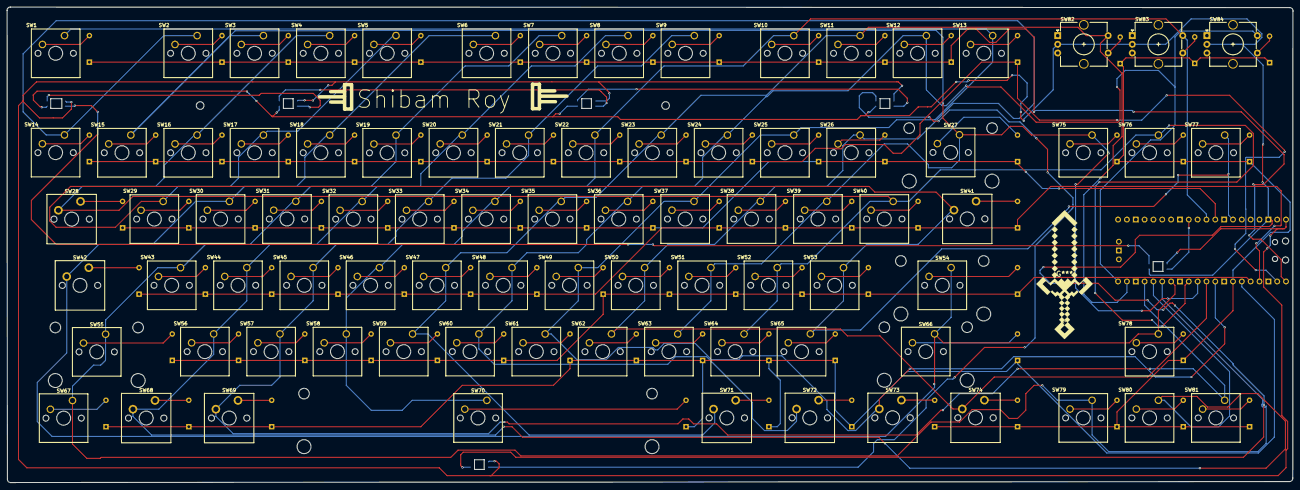
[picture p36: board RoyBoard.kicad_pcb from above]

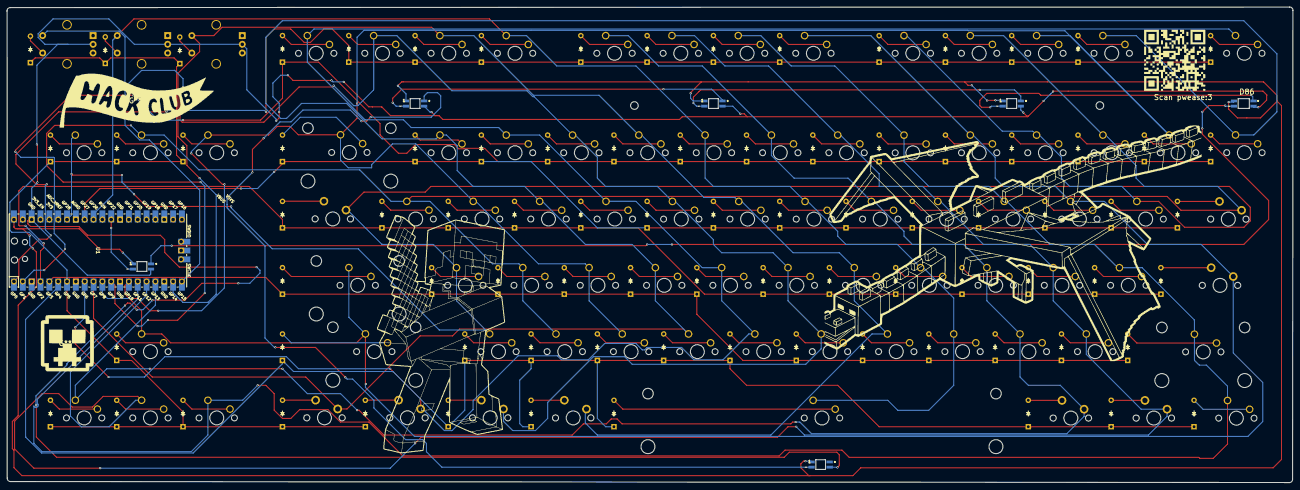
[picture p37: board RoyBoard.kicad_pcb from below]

Board: 2 copper layers, 369.5 x 136.6 mm, 175 parts (91 on the bottom side), 111 nets.

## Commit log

2025-03-27 Completed keyboard
    [D1, Diode, Schottky, Raspberry Pi Pico-R3.SLDPRT, D2, QSME-C194, LED, Raspberry Pi Pico-R3.SLDPRT, L1, Inductor, Raspberry Pi Pico-R3.SLDPRT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]
2025-03-27 Restructured everything
    [D1, Diode, Schottky, Raspberry Pi Pico-R3.SLDPRT, D2, QSME-C194, LED, Raspberry Pi Pico-R3.SLDPRT, L1, Inductor, Raspberry Pi Pico-R3.SLDPRT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]
2025-06-10 Added readme and changed silkscreen
    [RoyBoard-B_Cu.gbr, RoyBoard-B_Mask.gbr, RoyBoard-B_Paste.gbr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]
2025-06-27 Added CAD models, firmware and 3d renders
    [Bottom-RoyBoard.stl, Plate-RoyBoard.stl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]
2025-06-27 Added BOM and layout
2025-06-27 Added BOM in csv format, and updated readme
    [BOM.csv]
2025-10-16 Added new minecraft themed silkscreen
    [RoyBoard.kicad_pcb]
2025-10-17 Updated switches
2025-10-17 Updated CSV
    [BOM.csv]
2025-10-23 Updated BOM
2025-10-23 updated footprints to SK6812MINI-E
    [RoyBoard-B_Cu.gbr, RoyBoard-B_Mask.gbr, RoyBoard-B_Paste.gbr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]
2025-10-23 added new screenshots
    [RoyBoard.kicad_pcb]
2025-10-23 Updated CSV BOM
    [BOM.csv]
2025-10-23 Fixed total price positions
    [BOM.csv]
2025-10-23 Fixed INR total
    [BOM.csv]
2025-11-01 track step files with Git LFS
    [Bottom-RoyBoard.3mf, Bottom-RoyBoard.stl, Bottom.step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]
2025-11-01 added other files with lfs tracking
    [Royboard-Full.step]
2025-11-01 Added new gerbers
    [RoyBoard-B_Cu.gbr, RoyBoard-B_Mask.gbr, RoyBoard-B_Paste.gbr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]

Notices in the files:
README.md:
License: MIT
